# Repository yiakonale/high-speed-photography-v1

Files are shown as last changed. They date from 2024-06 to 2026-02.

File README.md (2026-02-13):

# High Speed Photography Unit V1

The problem with capturing high-speed photos boils down to how fast the camera can sample the subject. In nearly all cameras digital or analog, it comes down to the shutter speed. The shutter speed dictates how long the sensor (analog or digital) is exposed for, and therefore the "speed" of the photo. Regular digital cameras can expose a photo to 1/250 or 1/500 of a second. The fastest camera I own is an SLR with a mechanical shutter that can do 1/4000 of a second, which means that the film is exposed for 250us. One can optimize for faster and faster shutter speeds but the next bottleneck becomes the sensor itself. The less time you expose for, the less light the sensor can absorb. You can optimize for maximum light sensitivity but that's when the cost also skyrockets.

One workaround to this, is instead of relying on an ultra-fast shutter for quick exposure, instead using an ultra-fast light source to expose the event. The camera is set up to take a long exposure with large aperture and in complete darkness. When the event is you wish to capture takes place, the light source is triggered and exposes the scene for a very short instant. This works in the reverse way as before, as we now control the light source and leave the shutter wide open. The advantage to doing this is that you can use any regular camera, so long as you can take a long exposure. In order to know when you should pulse the light source, you need a way of knowing when your event is taking place, and very quickly triggerring a flash of light. A good video explanation of this concept can be found [here](https://www.youtube.com/watch?v=P-4pbFcERnk).

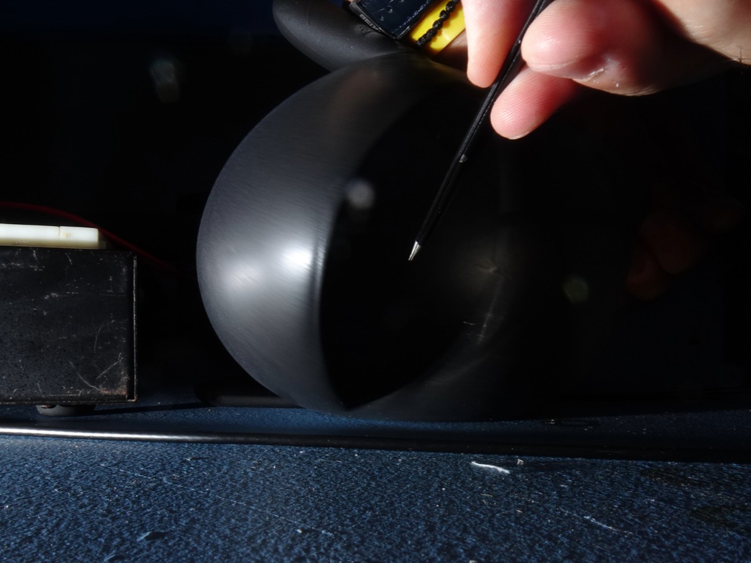
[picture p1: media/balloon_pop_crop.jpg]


A reliable way of quickly detecting when to trigger the light source is to use acoustic waves or sound. The only downside to this is that the event itself has to produce some kind of noise or sound at the instant we wish to capture. Fortunately, there are many such events that produce a noise such as a balloon pop, champagne popping, things smashing into other objects, etc.
To capture a clean photo an event, we need to produce a pulse of light to expose the scene. The difficulty is creating a flash which is both bright enough and short enough to not cause blurring. Fortunately modern camera flashes are more than capable of producing sharp, bright flashes in an instant. Such flashtubes commonly contain high-pressure xenon gas in a sealed glass tube that get ionized by a pulse of high-voltage, momentarily allowing a large amount of current to flow through the tube which creates the bright flash. The gas can be ionized by wrapping a coil of wire around the glass tube and pulsing high-voltage. The high-voltage can capacitively couple through the gas and create plasma. The ends of the flashtube are also connected to a high voltage DC source, usually a capacitor. When the plasma is initially created, the strong electric field inside the tube accelerates the charged particles, creating a cascading avalanche effect until all or most of the gas is ionized. Once a low impedance connection is established through the plasma, the capacitor can rapidly discharge through the glass, heating it in the process and creating a bright flash of light.

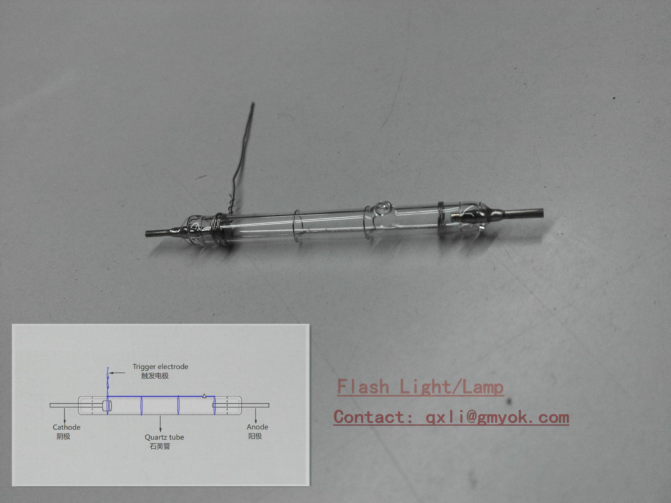
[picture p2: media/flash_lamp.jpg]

###### Source: https://www.ecplaza.net/products/xenon-flash-lamp_3895024

To make this work, we need 3 main components. The first is a sound detector that can sense changes in air pressure that will generate the signal for the light to flash. We want this to be sensitive enough to detect sounds from a few meters distance, but not too sensitive to avoid accidental misfires. Something adjustable would be ideal. The second is a trigger circuit that can ionize the flashtube when the signal is sent by the detector. A trigger transformer in combination with an electronic switch is often used to create the HV pulse. I salvaged the trigger transformer, high-voltage capacitor as well as the flashtube from an old digital camera, though I've also seen them being used in wall mounted fire alarm sirens like [this one](https://www.shutterstock.com/video/clip-10242920-fire-alarm-emergency-flashing-light) as these use a similar circuit. You can actually just make out the coil of wire around the flashlamp in the center. You can also buy the entire circuit on [Ebay](https://www.ebay.ca/itm/125804677365). Lastly, we'll need a step-up converter to charge our capacitor, usually in the range of 300-400V and a few tens of microfarads.

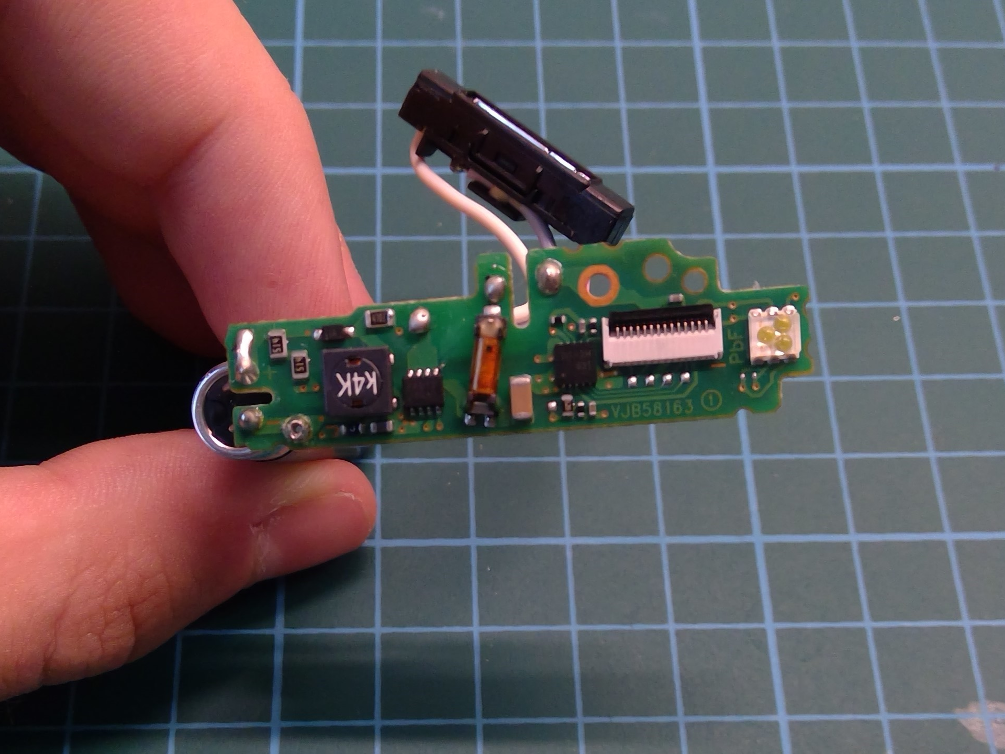
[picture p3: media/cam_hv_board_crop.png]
  
###### (Left) Digital camera opened with high-voltage module and flashlamp visible in the middle (Right) Holding the high-voltage module from its HV capacitor. Trigger transformer visible in the middle of the PCB (orange). Flashtube visible just behind with its 3 wires: +, -, HV trigger.

I decided to design 3 PCBs, one for each subcircuit and then connect them together somehow. Not a lot of thought went into this phase as will be evident later on. The trigger circuit is really simple. It consists of an electronic switch, in this case a thyristor that can safely control the high-voltage pulse. I've also seen this being done with IGBTs but thyristors are easier to find for this application. To create the high voltage pulse, we need a high turn-ratio transformer, as well as a series capacitor. This small capacitor slowly charges through a resistor and rapidly discharges through the primary of the transformer, creating a high voltage spark on the output, similar to an electrostatic discharge. This is enough to break down the gas inside the tube.

TODO:
- trigger cct construction
- boost cct construction
- tuning capacitance

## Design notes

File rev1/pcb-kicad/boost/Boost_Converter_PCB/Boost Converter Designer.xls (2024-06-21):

Boost Converter Calculator
(3 seperate Calculators)
Frequency Calculator |  |  |  |  | Voltage Regulator
Input Voltage | 12 | Volts |  |  | Reference Voltage | 6 | V
Inductor Size | 130 | µH |  |  | Ra | 1000 | k
Peak Switch Current | 14 | Amps | *Absolute Maximum, 10% overhead is factored in later |  | Rb | 12 | k
Duty Cycle | 55 | % |  |  | Potentiometer | 10 | k
Required Switching Frequency | 4.029304029 | kHz |  |  | Max Voltage | 506.00 | V
Estimated Power output | 33.264 | Watts |  |  | Min Voltage | 278.73 | V
Inductance Calculator
Input Voltage | 12 | Volts
Frequency | 4 | kHz
Duty Cycle | 55 | %
Peak Inductor Current | 14 | Amps | *Absolute Maximum, 10% overhead is factored in later
Inductance | 130.95 | µH
Estimated Power output | 33.264 | Watts
Output Power Calculator
Input Voltage | 12 | Volts |  | High duty cycle, high voltage, low inductance and low frequency result in increased inductor current
Inductor | 130 | µH |  | Increased inductor current means more energy stored in the inductor, which is hopefully transferred to the load
Duty Cycle | 55 | %
Expected Efficiency | 80 | %
Frequency | 4 | kHz
Output Power | 33.51 | Watts
Peak Inductor Current | 12.69 | Amps

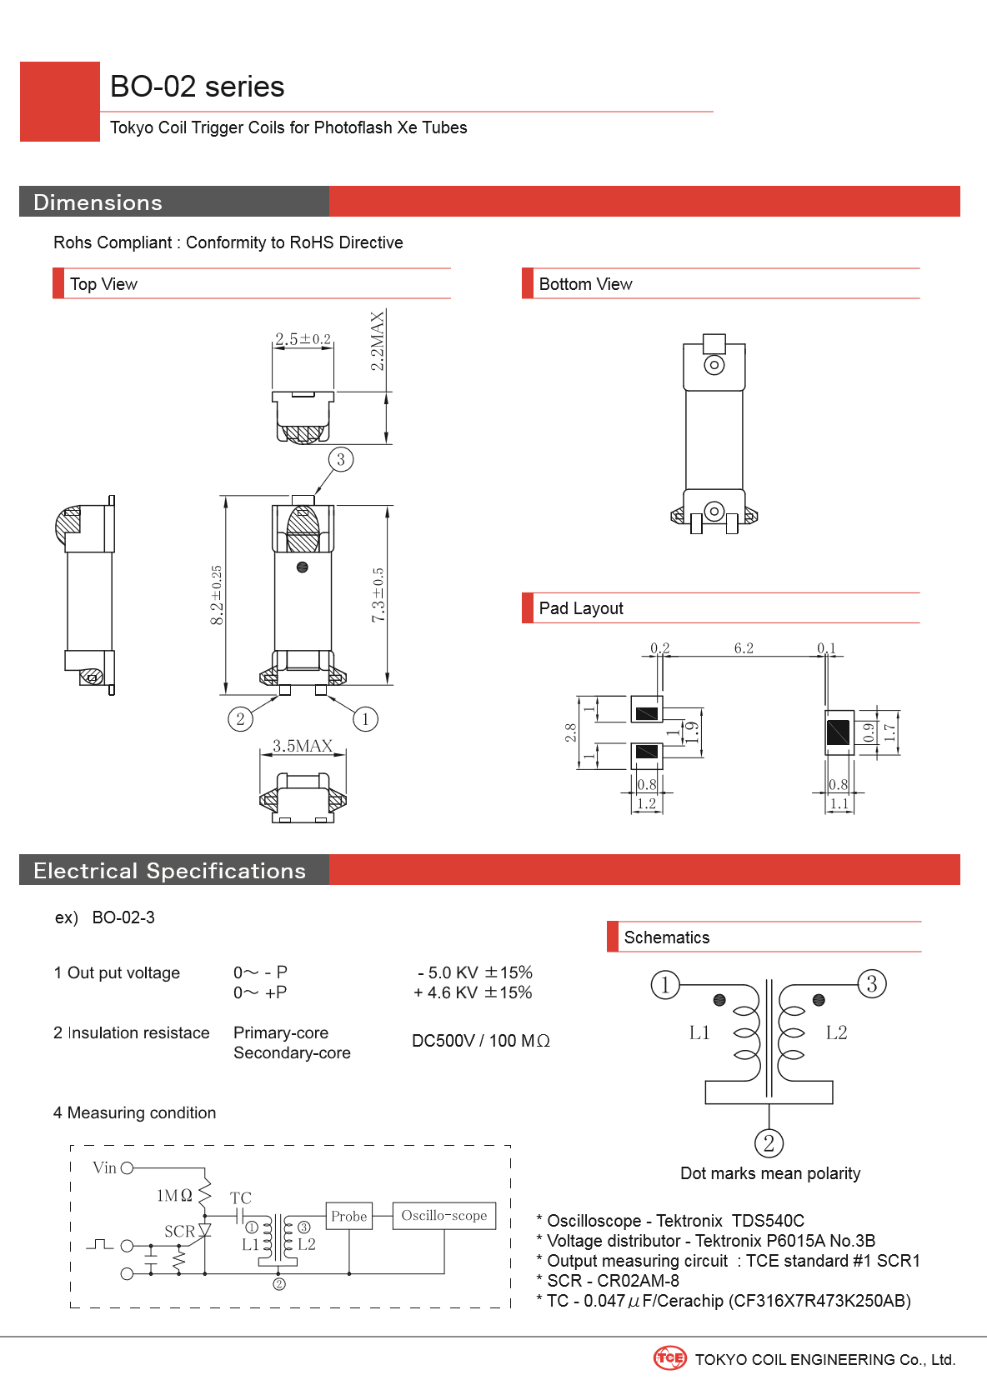
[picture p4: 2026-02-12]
media/BO-02-3_1.png

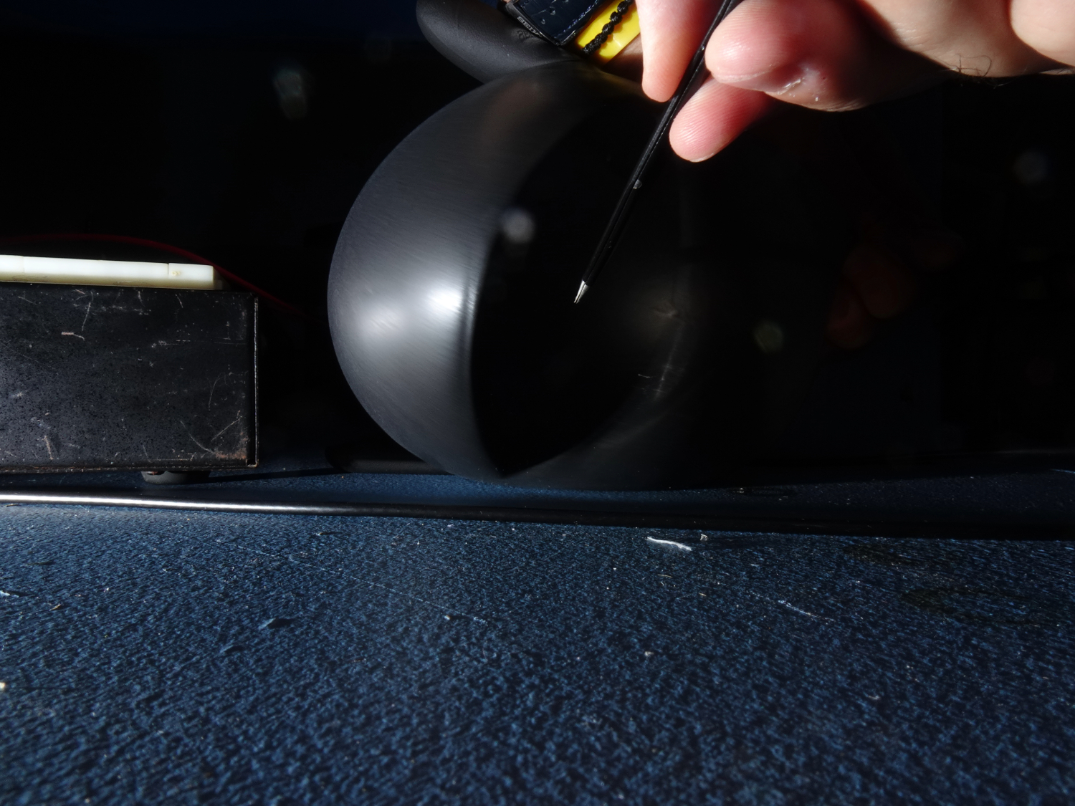
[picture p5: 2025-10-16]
media/balloon_pop.jpg

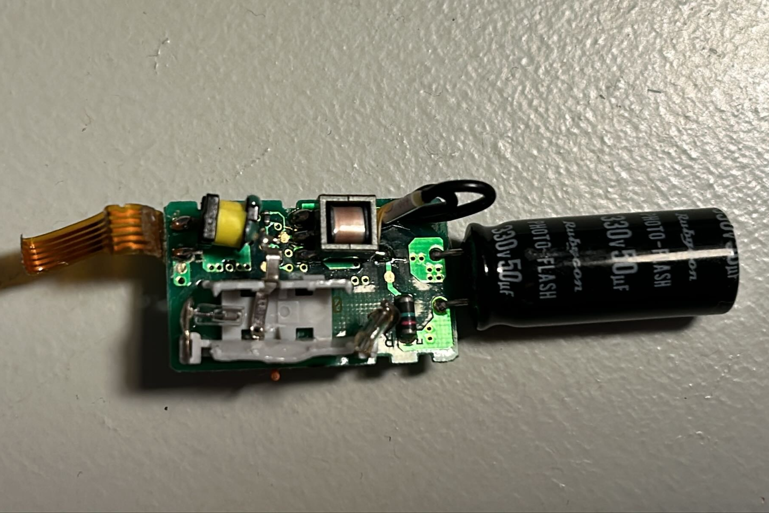
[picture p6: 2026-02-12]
media/alt_hv_board_crop.png

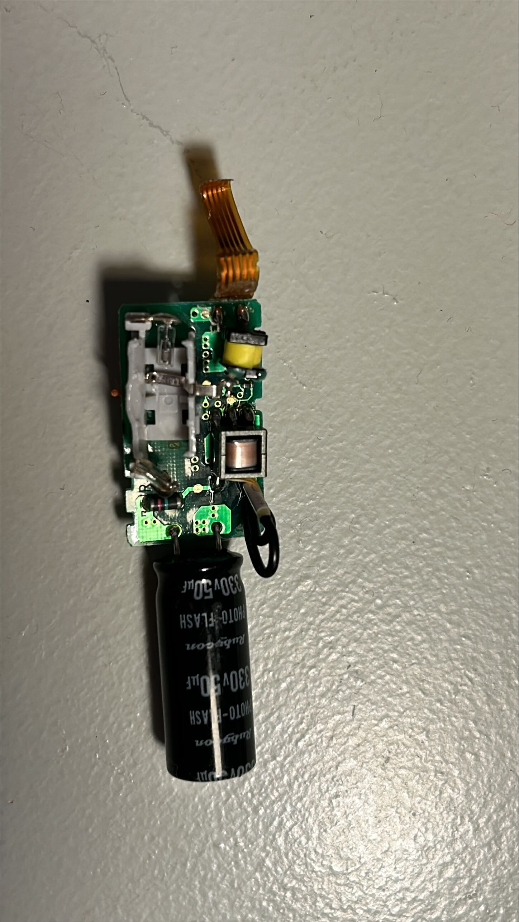
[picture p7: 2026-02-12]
media/alt_hv_board.png

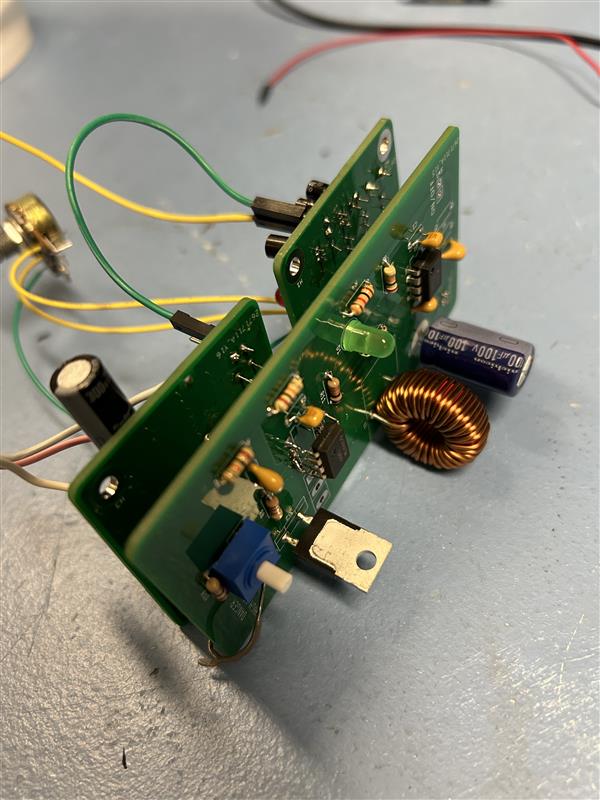
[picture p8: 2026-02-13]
media/assy_boost.jpg

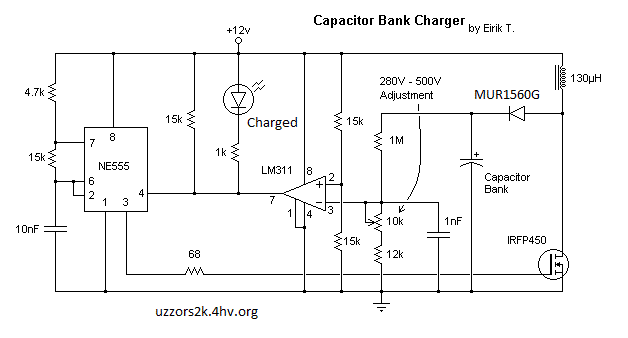
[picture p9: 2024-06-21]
rev1/pcb-kicad/boost/Boost_Converter_PCB/boost_converter 12v.gif

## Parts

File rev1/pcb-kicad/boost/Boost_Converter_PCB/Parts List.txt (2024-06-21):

C1	10nF	
C2	1nF	
C3	100uF	
D1	Green LED	
D2	SFA1608G		
L1	130uH	
Q1	IRFP450	
R1	15k	
R2	4.7k	
R3	15k	
R4	68	
R5	15k	
R6	15k	
R7	12k	
R8	10k	
R9	1M	
R10	1k	
U1	NE555	
U2	LM311	
W1	Ground (In)	
W2	12V in	
W3	Ground (Cap Bank)	
W4	Capacitor Bank +

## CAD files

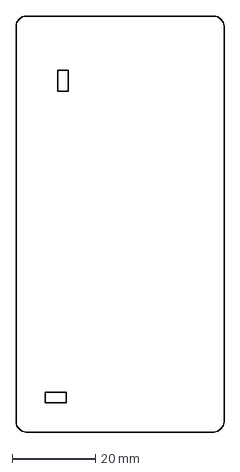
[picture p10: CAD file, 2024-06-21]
rev1/pcb-kicad/boost/Boost_Converter_PCB/flash_pcb.dxf
50.0 x 100.0 mm

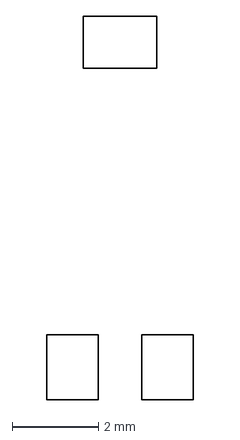
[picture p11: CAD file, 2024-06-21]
rev1/pcb-kicad/boost/Boost_Converter_PCB/trans.dxf
3.40 x 8.90 mm

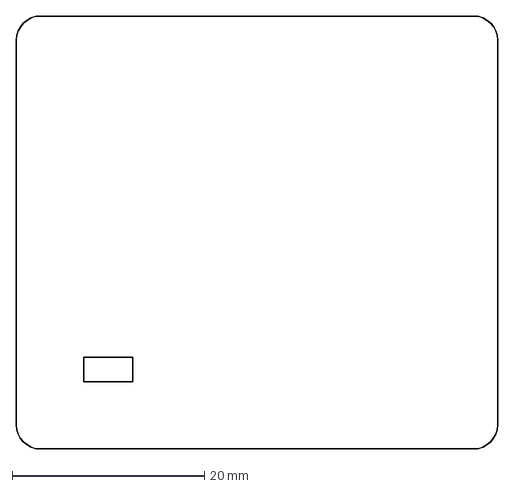
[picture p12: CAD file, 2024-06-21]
rev1/pcb-kicad/boost/Boost_Converter_PCB/trig_pcb.dxf
50.0 x 45.0 mm

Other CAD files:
rev1/pcb-kicad/hv-flash/hv_trans_footprint.ipt

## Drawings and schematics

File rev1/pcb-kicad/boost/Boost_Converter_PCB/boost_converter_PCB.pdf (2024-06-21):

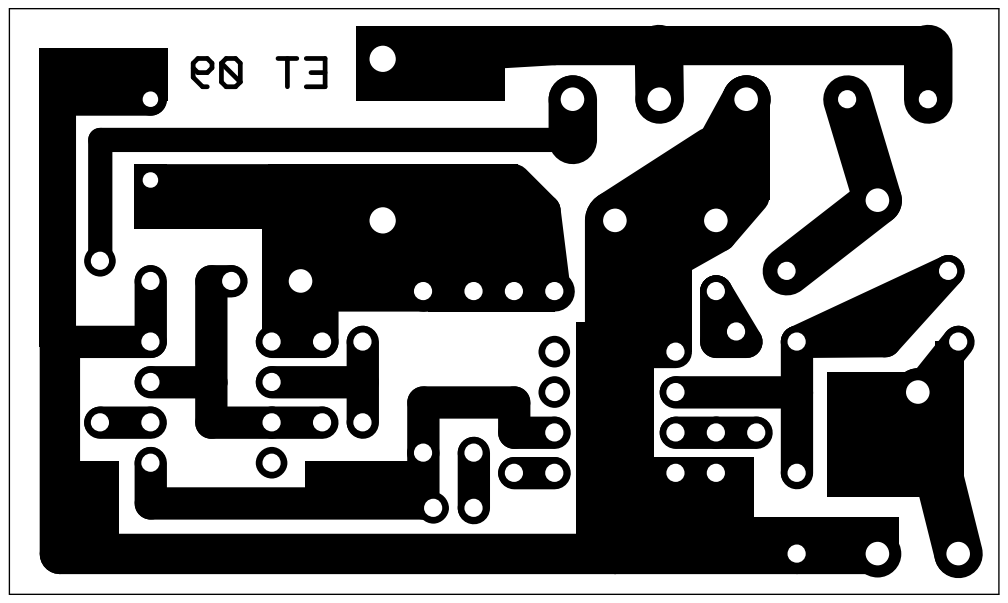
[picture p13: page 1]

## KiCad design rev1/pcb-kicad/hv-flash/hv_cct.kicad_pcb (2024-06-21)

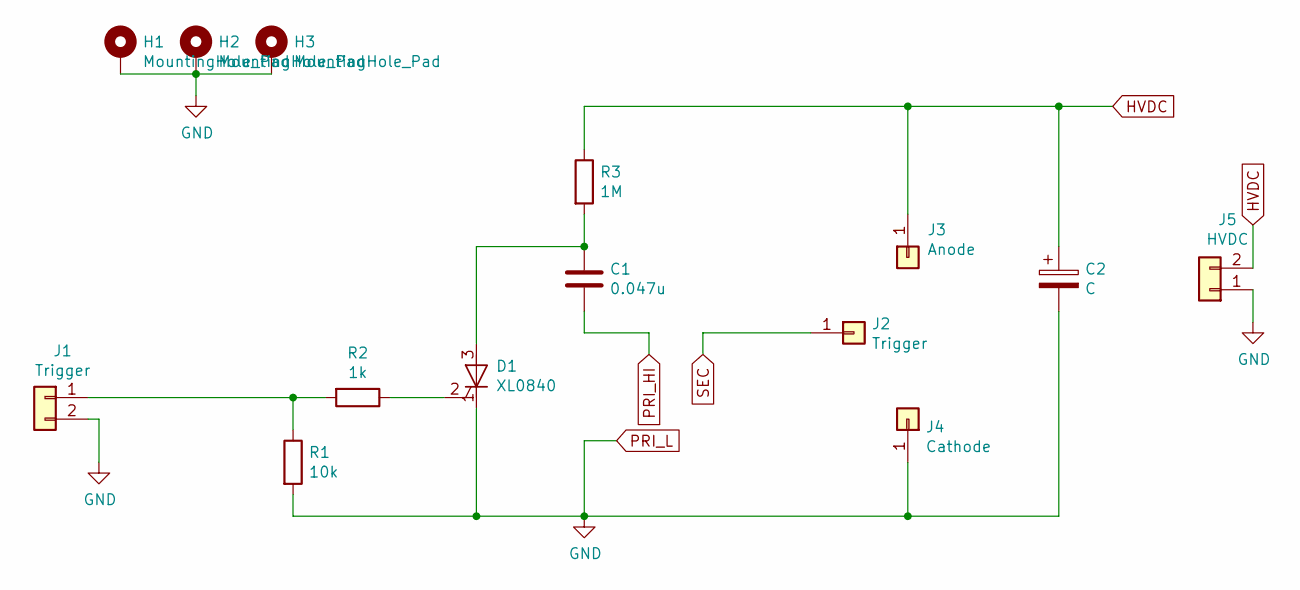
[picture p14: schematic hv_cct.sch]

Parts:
C1: 0.047u; C_Rect_L10.3mm_W5.0mm_P7.50mm_MKS4
C2: C; CP_Radial_D7.5mm_P2.50mm
D1: XL0840; TO-92_Inline_Wide
H1, H2, H3: MountingHole_Pad; MountingHole_3.2mm_M3_Pad
J1: Trigger; PinHeader_1x02_P2.54mm_Vertical
J2: Trigger; PinHeader_1x01_P2.54mm_Vertical
J3: Anode; PinHeader_1x01_P2.54mm_Vertical
J4: Cathode; PinHeader_1x01_P2.54mm_Vertical
J5: HVDC; PinHeader_1x02_P2.54mm_Vertical
R1: 10k; R_Axial_DIN0207_L6.3mm_D2.5mm_P7.62mm_Horizontal
R2: 1k; R_Axial_DIN0207_L6.3mm_D2.5mm_P7.62mm_Horizontal
R3: 1M; R_Axial_DIN0207_L6.3mm_D2.5mm_P7.62mm_Horizontal

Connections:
HVDC: C2.1, J3.1, J5.2, R3.1
unnamed: C1.1, D1.3 (A), R3.2
unnamed: D1.2 (G), R2.1
unnamed: J1.1, R1.1, R2.2
PRI_HI: C1.2
PRI_L: C2.2, D1.1 (K), H1.1, H2.1, H3.1, J1.2, J4.1, J5.1, R1.2
SEC: J2.1

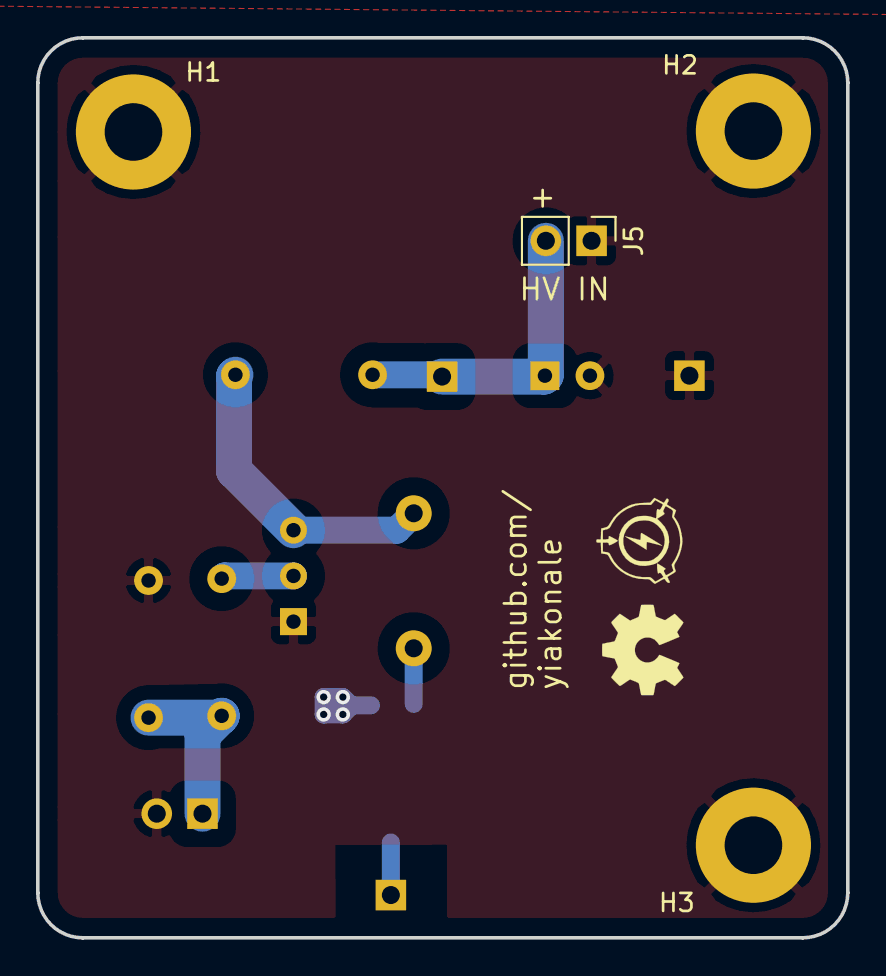
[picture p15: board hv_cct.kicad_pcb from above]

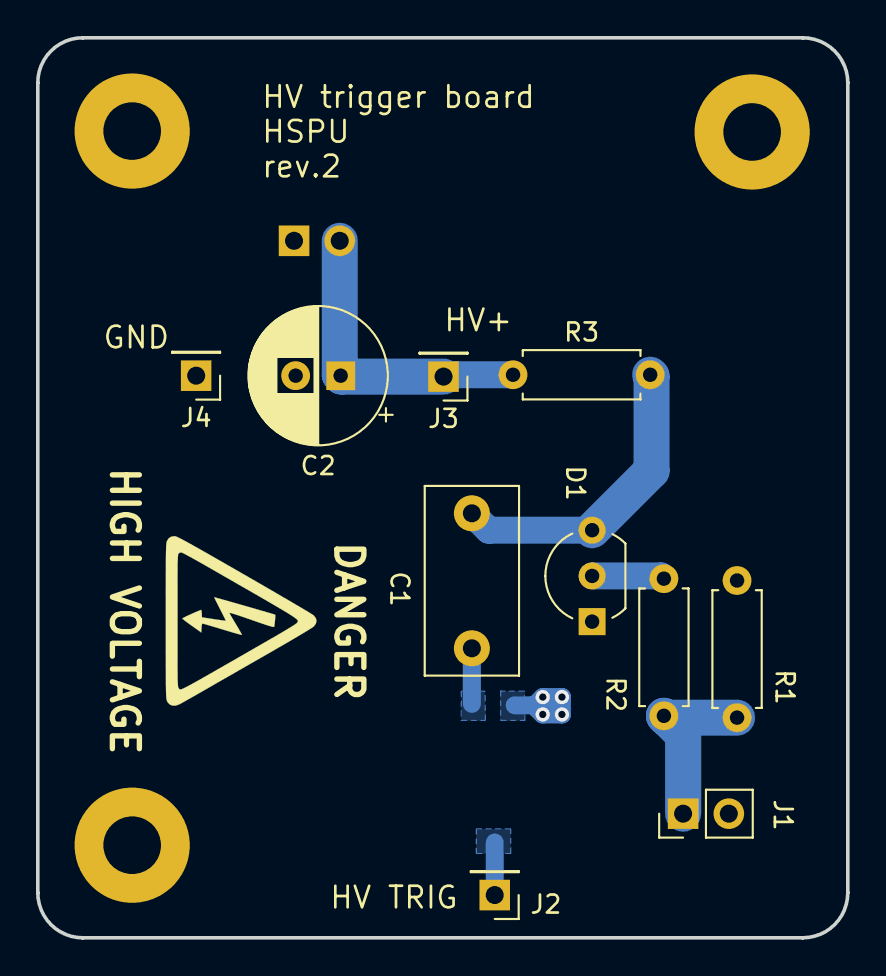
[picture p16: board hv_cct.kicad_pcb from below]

Board: 2 copper layers, 45.0 x 50.0 mm, 14 parts (10 on the bottom side), 5 nets.

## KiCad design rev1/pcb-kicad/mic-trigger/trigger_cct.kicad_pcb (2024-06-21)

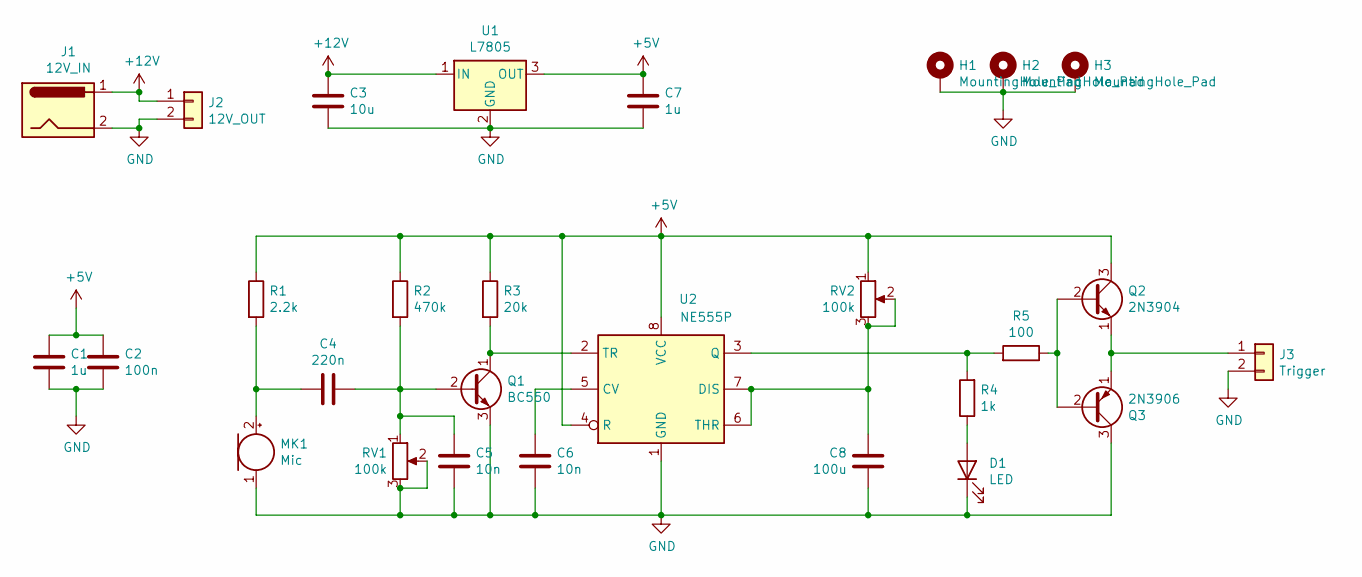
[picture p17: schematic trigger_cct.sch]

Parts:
C1: 1u; CP_Radial_D5.0mm_P2.00mm
C2: 100n; C_Disc_D5.0mm_W2.5mm_P5.00mm
C3: 10u; CP_Radial_D7.5mm_P2.50mm
C4: 220n; C_Disc_D5.0mm_W2.5mm_P5.00mm
C5, C6: 10n; C_Disc_D5.0mm_W2.5mm_P5.00mm
C7: 1u; CP_Radial_D5.0mm_P2.50mm
C8: 100u; CP_Radial_D7.5mm_P2.50mm
D1: LED; LED_D5.0mm
H1, H2, H3: MountingHole_Pad; MountingHole_3.2mm_M3_Pad
J1: 12V_IN; BarrelJack_Horizontal
J2: 12V_OUT; PinHeader_1x02_P2.54mm_Vertical
J3: Trigger; PinHeader_1x02_P2.54mm_Vertical
MK1: Mic; PinHeader_1x02_P2.54mm_Vertical
Q1: BC550; TO-92_Inline_Wide
Q2: 2N3904; TO-92_Inline_Wide
Q3: 2N3906; TO-92_Inline_Wide
R1: 2.2k; R_Axial_DIN0207_L6.3mm_D2.5mm_P7.62mm_Horizontal
R2: 470k; R_Axial_DIN0207_L6.3mm_D2.5mm_P7.62mm_Horizontal
R3: 20k; R_Axial_DIN0207_L6.3mm_D2.5mm_P7.62mm_Horizontal
R4: 1k; R_Axial_DIN0207_L6.3mm_D2.5mm_P7.62mm_Horizontal
R5: 100; R_Axial_DIN0207_L6.3mm_D2.5mm_P7.62mm_Horizontal
RV1, RV2: 100k; Potentiometer_Bourns_3296W_Vertical
U1: L7805; TO-220-3_Vertical
U2: NE555P; DIP-8_W7.62mm

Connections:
+5V: C1.1, C2.1, C7.2, Q2.3 (C), R1.1, R2.1, R3.1, RV2.1, U1.3 (OUT), U2.4 (R), U2.8 (VCC)
+12V: C3.2, J1.1, J2.1, U1.1 (IN)
GND: C1.2, C2.2, C3.1, C5.2, C6.2, C7.1, C8.1, D1.1 (K), H1.1, H2.1, H3.1, J1.2, J2.2, J3.2, MK1.1 (-), Q1.3 (E), Q3.3 (C), RV1.2, RV1.3, U1.2 (GND), U2.1 (GND)
unnamed: C4.1, C5.1, Q1.2 (B), R2.2, RV1.1
unnamed: C4.2, MK1.2 (+), R1.2
unnamed: C6.1, U2.5 (CV)
unnamed: C8.2, RV2.2, RV2.3, U2.6 (THR), U2.7 (DIS)
unnamed: D1.2 (A), R4.1
unnamed: J3.1, Q2.1 (E), Q3.1 (E)
unnamed: Q1.1 (C), R3.2, U2.2 (TR)
unnamed: Q2.2 (B), Q3.2 (B), R5.1
unnamed: R4.2, R5.2, U2.3 (Q)

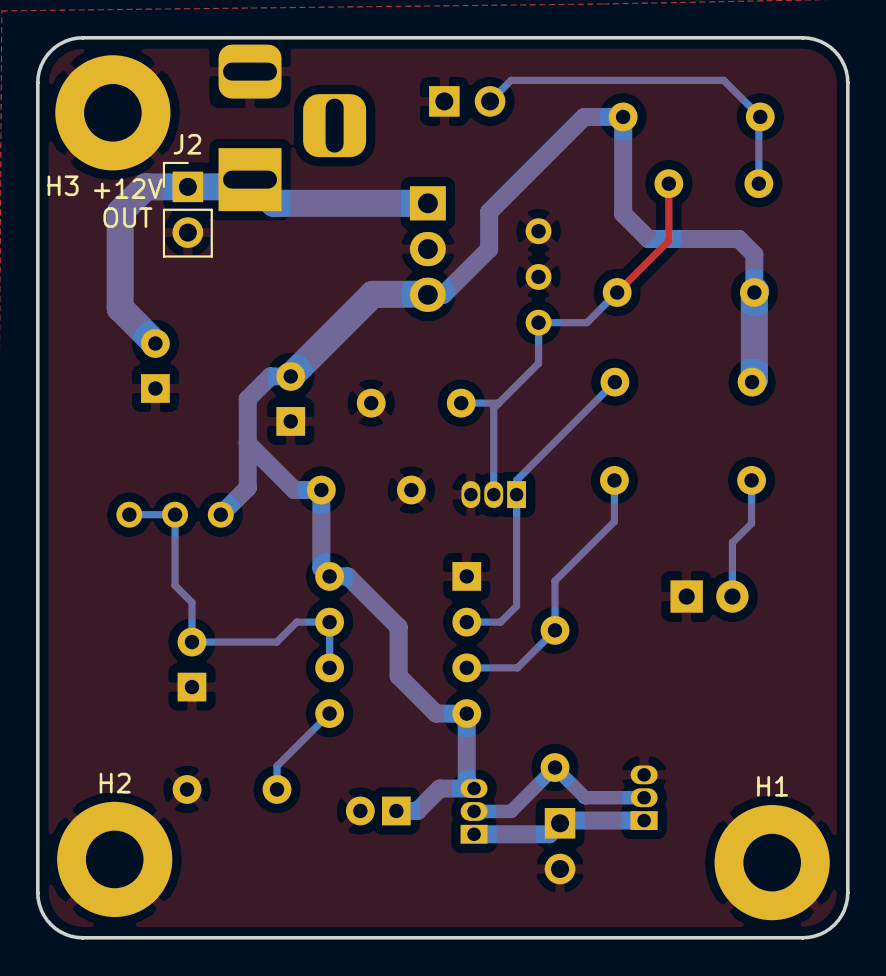
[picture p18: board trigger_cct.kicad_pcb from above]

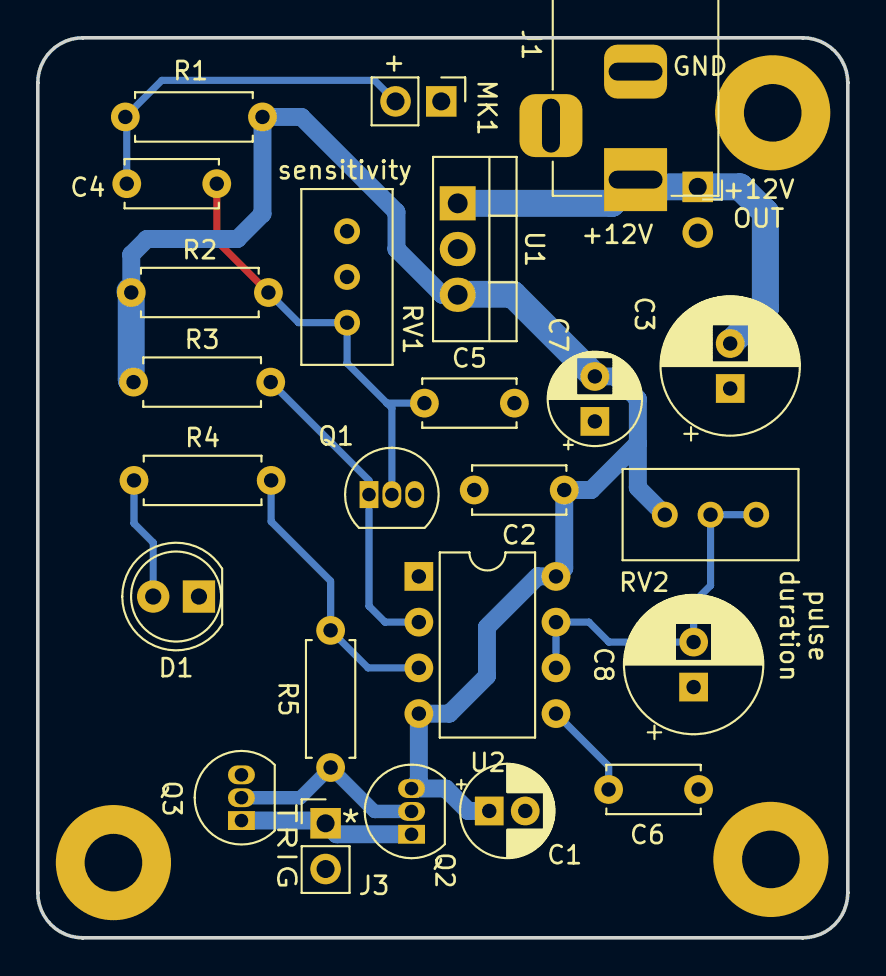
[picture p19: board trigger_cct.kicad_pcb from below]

Board: 2 copper layers, 45.0 x 50.0 mm, 28 parts (24 on the bottom side), 12 nets.

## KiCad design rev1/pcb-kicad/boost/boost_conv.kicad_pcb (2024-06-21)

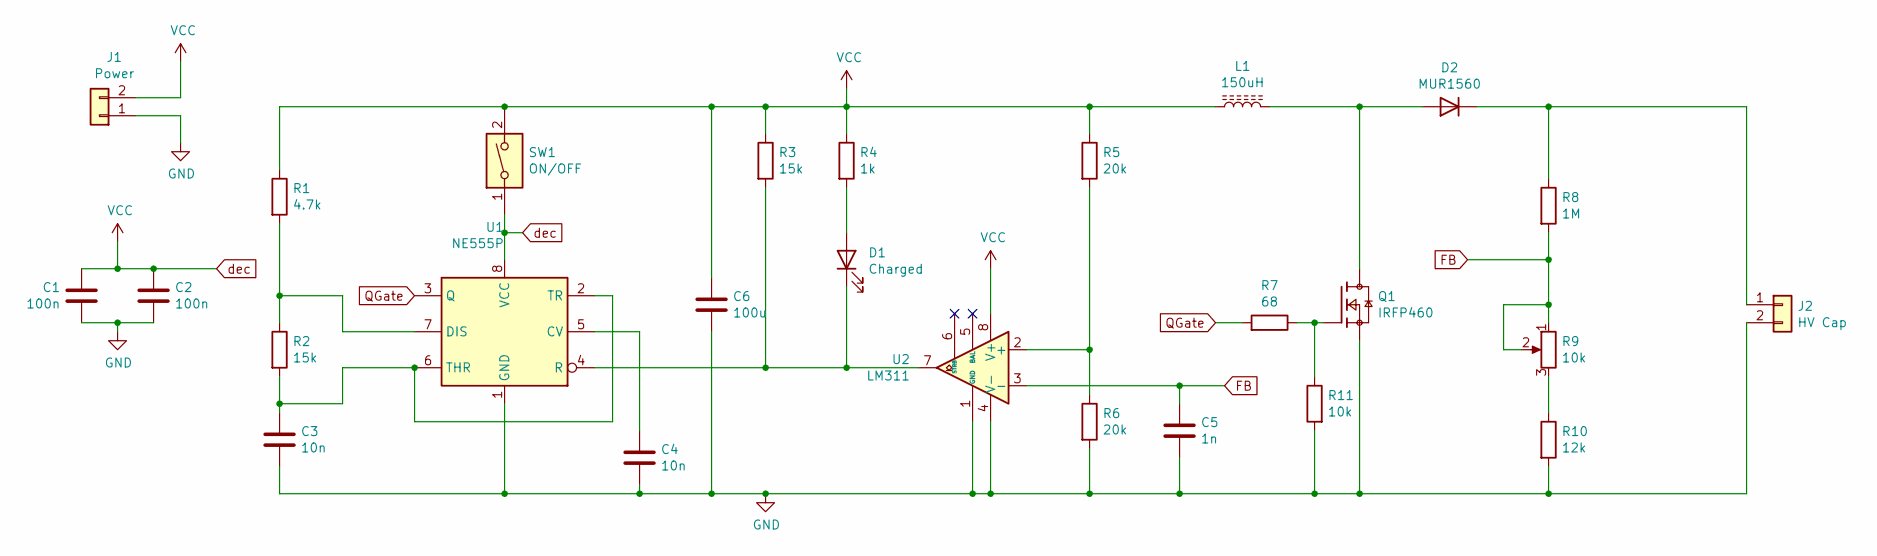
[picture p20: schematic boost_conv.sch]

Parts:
C1, C2: 100n; C_Disc_D5.0mm_W2.5mm_P5.00mm
C3, C4: 10n; C_Disc_D5.0mm_W2.5mm_P5.00mm
C5: 1n; C_Disc_D5.0mm_W2.5mm_P5.00mm
C6: 100u; CP_Radial_D8.0mm_P2.50mm
D1: Charged; LED_D5.0mm
D2: MUR1560; TO-220-2_Vertical
J1: Power; PinHeader_1x02_P2.54mm_Vertical
J2: HV Cap; PinHeader_1x02_P2.54mm_Vertical
L1: 150uH; L_Toroid_Vertical_L26.7mm_W14.0mm_P10.16mm_Pulse_D
Q1: IRFP460; TO-247-3_Vertical; PARTREV A
R1: 4.7k; R_Axial_DIN0207_L6.3mm_D2.5mm_P7.62mm_Horizontal
R2, R3: 15k; R_Axial_DIN0207_L6.3mm_D2.5mm_P7.62mm_Horizontal
R4: 1k; R_Axial_DIN0207_L6.3mm_D2.5mm_P7.62mm_Horizontal
R5, R6: 20k; R_Axial_DIN0207_L6.3mm_D2.5mm_P7.62mm_Horizontal
R7: 68; R_Axial_DIN0207_L6.3mm_D2.5mm_P7.62mm_Horizontal
R8: 1M; R_Axial_DIN0207_L6.3mm_D2.5mm_P7.62mm_Horizontal
R9: 10k; Potentiometer_Bourns_3296W_Vertical
R10: 12k; R_Axial_DIN0207_L6.3mm_D2.5mm_P7.62mm_Horizontal
R11: 10k; R_Axial_DIN0207_L6.3mm_D2.5mm_P7.62mm_Horizontal
SW1: ON/OFF; PinHeader_1x02_P2.54mm_Vertical
U1: NE555P; DIP-8_W7.62mm
U2: LM311; DIP-8_W7.62mm

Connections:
FB: C5.1, R8.2, R9.1, R9.2, U2.3 (-)
GND: C1.2, C2.2, C3.2, C4.2, C5.2, C6.2, J1.1, J2.2, Q1.3, R6.2, R10.2, R11.2, U1.1 (GND), U2.1 (GND), U2.4 (V-)
unnamed: C3.1, R2.2, U1.2 (TR), U1.6 (THR)
unnamed: C4.1, U1.5 (CV)
unnamed: D1.1 (K), R3.2, U1.4 (R), U2.7
unnamed: D1.2 (A), R4.2
unnamed: D2.1 (K), J2.1, R8.1
unnamed: D2.2 (A), L1.1, Q1.2
unnamed: Q1.1, R7.1, R11.1
unnamed: R1.2, R2.1, U1.7 (DIS)
unnamed: R5.2, R6.1, U2.2 (+)
unnamed: R9.3, R10.1
QGate: R7.2, U1.3 (Q)
dec: C1.1, C2.1, C6.1, J1.2, L1.2, R1.1, R3.1, R4.1, R5.1, SW1.1, SW1.2, U1.8 (VCC), U2.8 (V+)

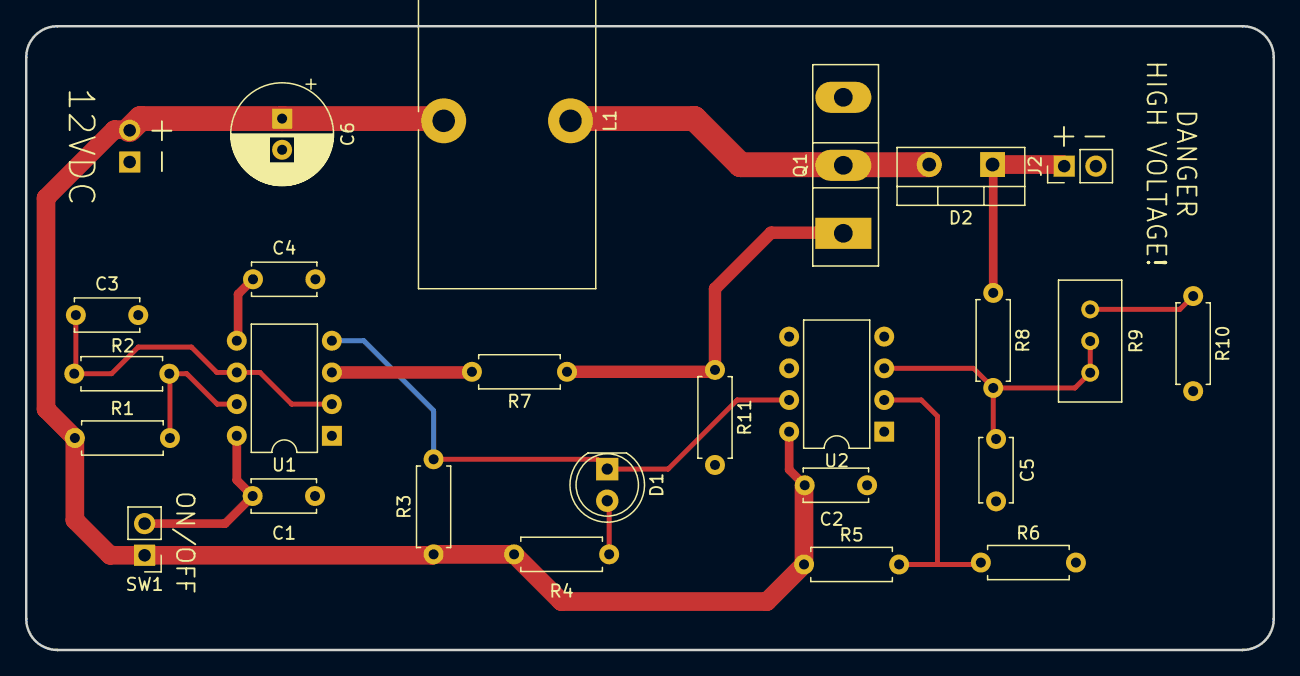
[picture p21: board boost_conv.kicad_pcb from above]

Board: 2 copper layers, 100.0 x 50.0 mm, 26 parts (1 on the bottom side), 14 nets.
